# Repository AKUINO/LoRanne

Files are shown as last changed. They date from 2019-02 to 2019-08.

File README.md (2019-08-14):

# Long Range (LoRa) Radio Sensors for AKUINO
After connecting wired 17 sensors to a single AKUINO, we were convinced that wireless is very useful...

With the advent of LoRA transmission technology which ensures a really good indoor range, with the availability of ready to use modules like AdaFruit Feather M0 able to transmit data for years with simple batteries, we are convinced that a very performant solution can be created.
## Hardware

Transmitters (working on batteries, collecting and transmitting sensors data, sleeping most of the time) are explained further here: https://github.com/AKUINO/RadioSensor/tree/master/transmitter

Receiver(s) (powered, collecting transmitted data, archiving it locally, transmitting on Internet, never sleeping) is explained further here: https://github.com/AKUINO/RadioSensor/tree/master/receiver

General design considerations:

* Transmitters: Arduino MKR WAN 1300 https://store.arduino.cc/mkr-wan-1300 (was AdaFruit Feather M0: https://www.adafruit.com/product/3179 but AdaFruit products are rarely certified "CE")
* Receiver: for transmitters, we are also switching to an integrated "CE" marked product, M5STACK Code Module: https://m5stack.com/collections/m5-core
* 1-Wire sensors have the advantage of being self-identified, "hot-pluggable" and could be connected to one sensor node or another: https://www.maximintegrated.com/en/app-notes/index.mvp/id/4206
  * Serial adapter for 1-Wire gives better reliability than bit-banging (e.g. https://www.mikroe.com/uart-1-wire-click ) but requires 5V. As most 1-Wire devices are happy (but sometimes slower) at 3.3V, fewer devices not too far away will make bit-banging possible.
  * Thermocron (IButton: https://be.farnell.com/fr-BE/c/semiconducteurs-circuits-integres/memoires/accessoires-iboutons/iboutons ) can receive a "mission" and record temperature OFF-LINE for very long period of time: they can be used to ensure cold-chain continuity during transportation. They can even be programmed by a remote radio module: http://arduinofun.blogspot.com/2010/04/arduino-ibutton-data-logger-programmer.html . We have programmed data download and missioning of Thermocron by ELSA
  * Mains Switch: https://www.axiris.eu/en/index.php/1-wire/1-wire-mains-switch
* I2C sensors are often working at 3.3V and 5V. Short wires though (20 cm max: should be in the same box than the radio module)
  * I2C CO2+temperature+humidity: https://befr.rs-online.com/web/p/products/1720552/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|Temperature_And_Humidity_Sensors-_-PRODUCT_GROUP&matchtype=&pla-544508151584&gclid=Cj0KCQiAzKnjBRDPARIsAKxfTRA_NGOGs_dE9fBuCA61ZyCIf1GovlkXcqFPyUBE3JYgCDP7rXKEHxUaAuaREALw_wcB&gclsrc=aw.ds
  * I2C Temperature and/or humidity: https://befr.rs-online.com/web/c/semiconductors/sensor-ics/temperature-sensors-humidity-sensors/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,4294510394,4294490065,4294505396,4294510395,4294510203,4294356324,4294821500 and also https://www.tindie.com/products/akdracom/temperature-humidity-sensor-probe-precision-ic/
  * Grove Wiring standard is often used and is similar to QWIIC from Sparkfun: https://www.sparkfun.com/qwiic (Grove as a normal pitch connector, Sparkfun is smaller; Beware: AdaFruit standard is different!):
  1. Yellow - SCL
  1. White - SDA (Blue for QWIIC)
  1. Red - VCC on all Grove Connectors
  1. Black - GND on all Grove Connectors
  M5Stack Core is equipped with a Grove I2C connector.
* Lithium Battery: https://shop.mchobby.be/accu-et-regulateur/746-accu-lipo-37v-4400mah-3232100007468.html , https://be.farnell.com/fr-BE/mikroelektronika/mikroe-1120/batterie-lithium-polymer-3-7v/dp/2786900 , https://www.onlylipo.com/21-1s-37-volts-1-element
* Enclosures:
  * We selected KRADEX 64mm x 88mm x 42mm: https://www.tme.eu/fr/details/z-56jh-abs/boitiers-universels/kradex/z56jh-abs/ looking like CEL-MAR 1-Wire boxes that we also use.
  * 8 x 8cm, 5cm deep: many electrical junction boxes
  * 10 x 10cm, 6cm deep: http://be.farnell.com/fr-BE/fibox/pcm-95-60-g/coffret-boite-polycarbonate-gris/dp/2473443

## Software
* RadioHead libraries: http://www.airspayce.com/mikem/arduino/RadioHead/index.html Be sure to use the latest version (1.89)
  * for LoRa: http://www.airspayce.com/mikem/arduino/RadioHead/classRH__RF95.html

* 1-wire:
  * Host driver: https://www.maximintegrated.com/en/products/ibutton/software/1wire/wirekit.cfm
  * Recommended by Adafruit: https://www.pjrc.com/teensy/td_libs_OneWire.html
  * Slave device emulation library: https://github.com/orgua/OneWireHub (in case we want to connect to host through 1-wire)

* AdaFruit Feather M0, Arduino IDE SAMD support: https://learn.adafruit.com/adafruit-feather-m0-basic-proto/using-with-arduino-ide

## LoRa
* Allowed duty cycle and power in different 868MHz bands: https://www.disk91.com/2017/technology/internet-of-things-technology/all-what-you-need-to-know-about-regulation-on-rf-868mhz-for-lpwan/ From this document, the best local bandwidth could be 869,3 to 869,4 limited to 10mW but with no duty cycle constraint.
  * We measured 7 packets of 37 characters per seconds when testing this radio band.  
* 433 MHz may not be allowed in production within Europe: the project may have to be announced as "RFID" if we stick to those frequencies
  * In this band, we reached 540 meters in a corn field (emmiter and receiver at the corn height; single wire antenna)
* Calculator of Allowed duty cycle for different LoRa configurations: https://docs.google.com/spreadsheets/d/1COg2J1at6j8meehTtvfj5TIiM8pbj4SvKf7sa-Oq5fU/edit#gid=1628588258
## Sensors
Each node can receive many kind of sensors and its firmware can be adapted for each situation: the USB programming port of the node can be used to either change the firmware or to access a terminal console and change parameters.

An important information is battery voltage: its value will always be read and transmitted (register 1).

### I2C
I2C runs on 5V but also on 3.3V (not all sensors but most). Wires must be kept very short (20cm max, less is better).

The commands are different for each type of sensors: the bus cannot be really "auto discovered" like with 1-Wire (see below). The only possible thing is to associate I2C addresses with possible devices...

### 1-Wire
1-Wire ensures auto-configuration (devices can be "discovered" on the bus). Each 1-Wire device have a unique 64 bits address which can be auto-discovered by polling the 1-Wire bus (owdir on Linux, the equivalent will have to be programmed using libraries like https://www.pjrc.com/teensy/td_libs_OneWire.html ). The 8 first bits of this address indicates a generic device type which will have to be known by the firmware to adapt itself to the characteristics of each device type (e.g. number of values, polling protocol, parasitic powering...). The 8 last bits are a CRC8 checksum of the 7 previous bytes. It must be verified after each transmission (wire or radio) to ensure data integrity.

List of existing device types: http://owfs.org/index.php?page=family-code-list

The device types that we really need to support at first are:
* 26 for the DS2438 Battery Monitor (used as an ADC for various types of sensors like RH, CO2...)
* 28 for the DS18B20 Temperature Sensor; a library directly supporting this device seems to exist: https://github.com/milesburton/Arduino-Temperature-Control-Library This may be the best way to start supporting some sensors...
* 01 for the DS1990 simulated by RFID badge reader

A central directory of 1-Wire devices will be kept locally but also in the Receiver (and in ELSA application).

Every minutes or 5 (or any delay set in configuration), the node will transmit the raw data (no scaling) read for the different sensors. The allocation table will be transmitted every hour (or delay set in configuration) or on request by the central node (after detection of a checksum mismatch with the allocation table).

Data will be processed by the sensor node to transmit only specific JSON data values like "temperature" and not all registers of the device.

## Messages
* Encryption: http://www.airspayce.com/mikem/arduino/RadioHead/classRHEncryptedDriver.html#details
* Header with:
  * "FROM" (for sensors, the id of current node; for central node, id to distinguish the right central node)
	  * encoded on one byte
  * "TO" (for sensors, id of their central node; for central node, 255 for broadcast or id of a specific node to be queried)
	  * encoded on one byte
  * "ID", for a given "FROM"-"TO"-"FLAGS" combination, is a sequence ID of the message (overflow at 255): it allows the receiver to detect it has missed messages (and take action to correct this situation if needed).
  * "FLAGS" specifies the type of message: sensors data vs actuators (registers) setting; retransmission request (messages missed by receiver, the receiver signals which ID are missing); devices table to identify connected 1-Wire or I2C devices (from sensor node to central); relaying (MESH protocol, to be designed)
  * Sensors Data message: see below

## Sensors Data Messages
There are many encoding formats (see bottom of https://github.com/AKUINO/JBCDIC/blob/master/README.md ).

Please look at our proposal, the project AKUINO/JBCDIC: https://github.com/AKUINO/JBCDIC !

## Protocol
* A potential source of inspiration: https://github.com/fredilarsen/ModuleInterface/blob/master/documentation/Protocol.md
* A remote module (sensors) is sleeping most of the time (does not listen to radio) and awakens from time to time (around 3 minutes) to collect data and send it to the central module.
* A central module is listening all the time and sends actuators settings (or retransmission requests) only just after receiving sensors data from a remote module.
* The sender listen to the air and wait for silence (random delay) to avoid collision (this is done by the radio chip SX127x but needs to be configured. Looking at RadioHead library source code, it can be done: https://github.com/adafruit/RadioHead/blob/master/RH_RF95.h ). This is called LBT (Listen Before Talk).
* The message is sent using RadioHead library (encrypted but no ACK required).
* For remote module, the sender keeps listening for eventual input messages from the destination (actuators settings, sensors data retransmission requests) during a short period of time.
* If a remote module notices that some actuators settings are missing, it requests their retransmission.
* Sensor nodes send their 1-Wire / I2C Allocation table either periodically (about an hour), either when some connection changes is detected or whenever a request for it is received from the central node
* Retransmission request: timestamp + pairs of bytes for each ID intervals ("begin ID"-"end ID") that needs to be (re)transmitted. Overflow may occur (increment of 255 is 0) and "end ID" can be lower than "begin ID".
* Retransmission: message with exactly the same Header (TO, FROM, ID, FLAGS) and Payload than the one transmitted before

All nodes will be responsible to keep a buffer of the last messages (254 last messages for sensors and 254 last messages for actuators) they sent.

Redundancy of central module is possible: the two modules then share the same ID. A central module may not have received a package and therefore ask to retransmit a message well received by the other module: redundant transmissions are therefore discarded based on ID+timestamp.

## Configuration
We will use a serial terminal (USB) to set the configuration parameters (ANSI character codes for colors). We have the necessary code in C++ for PIC32. The configuration will have to assign a key (0 to 31) to the physically connected ports:
* Digital inputs: for a 1st version, we will statically map some GPIO as 0/1 ports
* Analog inputs (12 bits): for a 1st version, we will statically map some ADC inputs including at least the battery level and 2 ADC lines
* Digital outputs (PWM, pull-up, delays) to be SET (based on messages received from central): for a 1st version, we will statically map some PWM lines with basic local configuration attributes.
* 1-Wire (multiple sensors: 1-Wire addresses AUTOMATICALLY mapped to different keys but a selection of registries may have to be done based on the device type. ABANDONED for now due to lack of 5V...)
* Serial link (not for a 1st version except if a precise need arise)
* Campbell SDI (not for a 1st version except if a precise need arise)
* I2C device initialization command and register read: this is not well standardized but we will try to orthogonalize the possibilities.
A basic polling cycle (e.g. 3 minutes) has to be set. Each key can be obtained either at each poll or at a configured multiple.

## References
* The Ten Commandments of Wireless Communications: http://www.bb-elec.com/Learning-Center/All-White-Papers/Wireless-Cellular/10-Commandments-of-Wireless-Communications/10_Commandments_Wireless_WP033_R2-1112.pdf
* Detailed RadioHead interface: https://github.com/adafruit/RadioHead/blob/master/RH_RF95.h
* The standard pinout of Feather M0 is: https://cdn-learn.adafruit.com/assets/assets/000/046/244/original/adafruit_products_Feather_M0_Basic_Proto_v2.2-1.png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
* Similar project but for very long range: http://cpham.perso.univ-pau.fr/LORA/WAZIUP/FAQ.pdf
  * http://cpham.perso.univ-pau.fr/LORA/WAZIUP/SUTS-demo-slides.pdf
* CayenneLPP: https://mydevices.com/cayenne/docs/lora/#lora-cayenne-low-power-payload
* PJON, an alternative transmission protocol: https://github.com/fredilarsen/ModuleInterface/blob/master/documentation/Protocol.md
* PlugAndPlay mechanism for small IoT networks using "off the shelf" sensors: http://pitkaaho.net/varasto/2013_IJSNet.pdf
* MainFlux does not seems to be locking anything (to double check!) and is involved in FIWARE and is very near of a good gateway for ELSA: https://www.mainflux.com/index.html
* LORD-MicroStrain is locking by the hardware : https://github.com/LORD-MicroStrain/
* UbiWorX is locking by the platform: https://ubiworx.com/documentation/introduction/introduction.html
* W3C API: https://w3c.github.io/sensors/

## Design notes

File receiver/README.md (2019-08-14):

# Receiver (Data Sink)
One or more gateway (receiver) can collect the data emitted by the different transmitters (radio modules with sensors connected).

The receiver(s) is always listening (never sleeps) and responds immediately when it receives a message:
1. it acknowledges the received message
1. if a further answer is needed (current time for instance), it sends it immediately

The receiver is archiving all the messages it receives. This archive is stored on a SD card which may be removed (the receiver is therefore a data logger).

The receiver sends the received data to the ELSA web application (decompressed and re-expanded to valid JSON but without semantic interpretation). The archived data on the SD card is also useful when Internet is interrupted (even for a very long time): all data can be sent when comunications resume.

The receiver synchronizes its clock with Internet (when available) and store the current date/time in the local RTC.

A small OLED display shows the communication statuses (LoRa, Internet), the latest data received and the possible alarms.

## Hardware

The receiver is a simple stack of the following AdaFruit boards (from bottom to top):
1. SD Card and Real Time Clock: https://www.adafruit.com/product/2922
1. LoRa Radio: https://www.adafruit.com/product/3231
1. HUZZAH32 ESP32 Feather: https://www.adafruit.com/product/3405
1. 128x32 OLED Add-on For Feather: https://www.adafruit.com/product/2900

The enclosure is big enough to guest a 18650 battery for continuous operation even during a long power breakdown.

To have "CE" marked hardware, we will be using M5Stack Core module in the future. It integrates in a sleek package:

    USB Type-C connector (Power and Programming)
    ESP32-based: 4 MByte flash + 520K RAM
    Speaker, 3 Buttons, Color LCD(320*240), 1 Reset
    WiFi 2.4G Antenna: Proant 440
    SD card slot (16G Maximum size)
    Battery Socket & 150 mAh Lipo Battery
    Bus Extension Pins & Holes
    Grove Port

### Pinout

PCB Pin|ESP32 Pin|Remark
-------|---------|------
RST||MCU Reset
3V|Vcc|3V3 power, 250ma for MCU, 250ma available for all other boards
NC||Not connected
GND|GND|GROUND common to all boards
A0|GPIO 26|Relay 1 enable. ADC not working when Wifi works
A1|GPIO 25|Relay 1 disable. ADC not working when Wifi works
A2|GPI 34|Input only!
A3|GPI 39|Input only!
A4|GPI 36|Input only!
A5|GPIO 4|Relay 2 disable. ADC not working when Wifi works
SCK|CLCK|SPI Clock (LoRa)
MO|MOSI|SPI output (LoRa)
MI|MISO|SPI input (LoRa)
RX|RX|Serial1 input
TX|TX|Serial1 output
21|GPIO 21|Relay 2 enable
-------|---------|------
BAT||Battery power
EN||3V3 regulator enable (disable if 3V3 power provided in another way)
USB||USB connector power
13|GPIO 13|Red LED on main board
12|GPIO 12|Pull down resistor
27|GPIO 27|LoRa A=Reset LoRa
33|GPIO 33|LoRa B=ChipSelect SD card
15|GPIO 15|Button A;LoRa C
32|GPIO 32|Button B;LoRa D=InterrupReQuest LoRa
14|GPIO 14|Button C;LoRa E=ChipSelect LoRa
SCL|SCL|I2C Clock (no pull-up)
SDA|SDA|I2C Data (no pull-up). OLED address=0x3C. RTC address=0x68

## Software

The software is a mirror of the one used by the transmitter. It must:
1. acknowledge data received to connecting transmitters (RadioHead Datagrams)
2. TO EVALUATE: assign a reduced numerical id for every string (name, 1-Wire ID, I2C peripheral, etc.) submitted by a transmitter: this allows compression of strings that may need to be transmitted by Radio. If the receiver fails, the transmitters can provide their local part of the dictionary when it restarts.
3. TODO: it retrieves sensors configuration (for the parameters needed to be known locally if any) from the ELSA web application. Those parameters are archived on the SD card in case of Internet failure. Amongst those parameters, alarm levels for some sensors, set points for opening/closing valves or switches, etc.
4. it sends data to the ELSA web application (also archived on the SD card)

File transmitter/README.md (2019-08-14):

# TRANSMITTER
In a "star" network there are modules collecting data in different places (transmitters) and one or two "data sinks" (receivers, gateways) that route the data to the data management application.

The transmitters must be as autonomous as possible (minimal configuration, automatic adaptation to new sensors put in place, agnostic about the data: it will be managed by the application, not the transmitter).

They include:
* power management: sensors are powered only when needed, battery power is saved as much as possible
* radio bandwidth management: radio transmission is minimized and assumed "dangerous": if it fails, data is kept up to the moment transmission can resume.

The configuration needed is minimal:
* a Network ID is provided once for all and needs a special boot-up sequence and password to be changed.
* a Network access key and a unique Module ID must be set. They remain normally unchanged. Another password protects those parameters.

The peripherals are automatically detected (1-Wire, I2C). Some may have to be configured (Analog or serial inputs). This is done through a wizard (sequence of questions with current answers provided by defaults).

Radio messages are buffered and exchanged in compressed URL format (see project [JBCDIC](https://github.com/AKUINO/JBCDIC/blob/master/README.md), aimed at compressiong JSON, used to compress URLs).

The transmitter is currently based on the Adafruit Feather M0 with a LoRa transmitter (https://www.adafruit.com/product/3178) but next version will be based on Arduino MKR WAN 1300. We add an underlying board to ease connections to sensors and to selectively power them. The following table explains the pinout:

Connector|Code|Data Pin|Power Activation Pin|Remark
---------|----|--------|--------------------|------
J1-1|g|||GND
J1-2|T|TX (15)|A3 (8)|Serial TX, 10k pull-up
J1-3|R|RX (14)||Serial RX
J1-4|v||A3 (8)|Switched and limited Vcc (see below)
J1-5|g|||GND
J1-6|C|SCL (18)|D11 (23)|I2C clock, 5k pull-up
J1-7|D|SDA (17)|D11 (23)|I2C data, 5k pull-up
J1-8|v||D11 (23)|Switched and limited Vcc (see below)
J1-9|g|||GND
J1-10|O|D13 (25)||LED: Switched Vcc but limited (see below) and 100 ohm
J1-11|I|A0 (5)||Button switch; Analog input protected and filtered for 50Hz
J1-12|v|||Unswitched Vcc limited by 100 ohm
J2-1|g|||GND
J2-2|1|A1 (6)||Analog input protected and filtered for 50Hz
J2-3|v||A4 (9)|Switched and limited Vcc (see below)
J2-4|g|||GND
J2-5|2|A2 (7)||Analog input protected and filtered for 50Hz
J2-6|v||A5 (10)|Switched and limited Vcc (see below)
J2-7|g|||GND
J2-8|W|D5 (19)|D12 (24)|1-Wire bus, 5k pull-up
J2-9|v||D12 (24)|Switched and limited Vcc (see below)
J2-10|10|D10 (22)||Switched and limited Vcc (see below)
J2-11|6|D6 (20)||Switched and limited Vcc (see below)
J2-12|v7||D12 (24)|Switched 7 volts to power RFID/NFC reader (small DC/DC converter from D12)

Distributed power is switched by a TBD62783APG DMOS transistor array (clamping diode included), limited by a 300ma temporary fuse, a 18µH inductance and sustained by a 3µF capacitor.

Detailed Eagle schema and board definition are in this directory.

## Data transmitted

Data is encoded as an URL using JBCDIC ( https://github.com/AKUINO/JBCDIC ). A message is made of only one (for now) session of measures up to the LoRa maximum size (53 bytes in our case).

One measurements session is a URL (in the future: a JSON object) with the following properties:

Property|Connection|Pin|Description
--------|----------|---|-----------
H0|||Seconds ellapsed since module startup. H0 is replaced by H with the correct time by the receiver before resending to the Web application
H|||Seconds since 01/01/2019 (if time was broadcasted by receiver ("data sink") and synchronized with transmitter)
N|||Network Identification number: Not transmitted but added by the receiver before resending to the Web application
M|||Radio Module Identification number: Not transmitted but added by the receiver before resending to the Web application
R|||RSSI for this message: Not transmitted but added by the receiver before resending to the Web application
A0|J1-11|A0|Button pressed? Not transmitted if 0
A1|J2-2|A1|Analog input 1. Not transmitted if 0
A2|J2-5|A2|Analog input 2. Not transmitted if 0
B||A6|Battery voltage
B5||A7|USB voltage (if present). Usually 5 volts if connected
B9|||Last RSSI of messages broadcasted by Receiver (decimal)
C|J1-3|RX|Serial data received (string)
Dnnn|J2-8|D5|Value (or array of values or object with different properties) obtained from 1-Wire device at address "nnn..." (decimal)
G|J2-8|D5|Last badge read by RFID reader (encoded in decimal). Not transmitted if none
G0|J1-10|D13|Button LED on? Not transmitted if not
G1|J2-10|D10|Yellow LED of RFID reader is on? Not transmitted if not
G2|J2-11|D6|Red LED of RFID reader is on? Not transmitted if not
Innn|J1-7|I2C|Value (or array of values or object with different properties) obtained from I2C device at address "nnn" (decimal)

### Data transmission example

Before compression to 4 bits per character:
`{H0+3602A0+1B+3-12B9-78D159300978176+27-2I68[+27-5+40-5]}`
which means:
* `H0+3602` : 3602 seconds elapsed since starting the radio module
* `A0+1` : Button is pressed
* `B+3-12` : Battery is 3.12V
* `B9-78` : Last RSSI was -78 (in decimal)
* `D159300978176+27-2` : the temperature sensor address is 0x2517140600 (not including the leading 0x28 indicating its type and the trailing byte providing an CRC) and its temperature is 27.2°C
* `I68[+27-5+40-5]` : the I2C device at address 0x44 (usually an SHT31 sensor) provides two values: 27.5°C and 40.5% rH

The receiver will receive this data and retransmit it to the Internet application in standard JSON and adding network/module identification:

~~~~
  [ { H:(date/time in seconds elapsed since 1/1/1970 as in UNIX),
     N:1,   (network id)
     M:3,   (module id)
     R:-77,   (RSSI of transmitted message)
     A0:1,     
     B:3.12,    
     B9:-78,    
     D159300978176:27.2,    
     I68:[27.5,40.5]   
    } 
  ]
~~~~

## Software
* Radiohead library for encrypted Lora transmissions
* Protohead for simultaneous execution of data collection and radio transmission
* Periodical wake-ups for collection of sensors values and LoRa transmission (Listen before talk, random delay)
* USB Serial port for the configuration wizard
* JBCDIC for data compression
* FIFO Round Robin Buffer for unacknowledged transmitted data
* Watchdog on button for immediate wakeup, NFC/RFID scan and immediate transmission of status data (including the "button pressed" indication)

## Extensions
* To control equipement in adverse electrical environments, insulation of 1-Wire bus may be useful:  http://www.ti.com/lit/ds/symlink/iso1540.pdf

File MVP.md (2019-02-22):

# Capteurs Radio LoRa / Produit viable minimal

Afin de réaliser rapidement un produit qui réponde à 90% des besoins avérés, ce document en liste les caractéristiques ainsi que les étapes de réalisation.

Il est en français car il est à usage de l'équipe aux commandes à Gembloux en ce printemps 2019...

## Spécifications du matériel

1. Module AdaFruit Feather M0 LoRa 868 MHz
1. Batterie LiPo la plus puissante possible dans les limites de taille du boîtier qui sera choisi
1. Boîtier mural pouvant s'ouvrir (vis de serrage) pour faire passer les fils ou capteurs requis tout en gardant une étanchéité IP65 ou plus. S'inspirer de https://cdn-learn.adafruit.com/downloads/pdf/3d-printed-case-for-adafruit-feather.pdf
1. Connexions:
   1. Antenne interne ou externe ? Tester la différence de portée...
   1. Port USB "device" du AdaFruit Feather: pouvoir charger la batterie, pouvoir mettre à jour le logiciel, pouvoir configurer sans ouvrir le boîtier (bouchon en caoutchouc au dessus du port?) 
   1. Alimentation 3V3 commutable (MOSFET? Denis va nous conseiller) pour les périphériques ("high side" ou "low side"?)
   1. Périphériques I2C en chaîne (connecteurs Grove: 4=GND - 3=3V3 - 2=SDA - 1=SCL) de 20cm ou moins.
   1. Port RS-232 (balance, sonde pH, etc.) avec convertisseur de niveaux du genre MAX3232. Idéalement le signal DCE (ou autre?) devrait être lié à un GPIO indiquant si le micro-contrôleur est endormi ou non.
   1. (combien?) Ports GPIO en entrée ou en sortie (bornier à vis), protections sans doute nécessaire (décharges électrostatiques, surtensions, court-circuit...)
   1. (combien?) Ports ADC en entrée (bornier à vis), protections sans doute nécessaire (décharges électrostatiques, surtensions...)
   1. Plusieurs points de connexions devraient être prévus pour la terre (GND) et le VCC (ou le VCC commuté) afin de pouvoir assembler des composants discrets (résistances) pour protéger les entrées.
   1. Bouton "reset" ou ON/OFF pour redémarrer sans devoir ouvrir (panne) ? S'inspirer de https://cdn-learn.adafruit.com/downloads/pdf/on-slash-off-switches.pdf?timestamp=1550577849

## Spécifications du logiciel

1. Voir le README.md ...
1. On préallouera les registres de configuration et de réception des données (pas de nécessité de gérer une allocation dynamique pour le moment): voir plus loin
1. Réseau en étoile (pas de relais "MESH") avec un "data sink" Central (connexion à Internet) pour le moment
1. Bande 10mW (pas de limite d'utilisation)
1. Sortie du Central par le port USB (Série), une ligne par paquet reçu avec encodage "URL": ...?clé=valeur&clé=valeur...
1. Commandes de paramétrage aussi sous forme d'URL: ...?clé=valeur&clé=valeur&...&clé=valeur

## Tableau des Périphériques ("output" du module)

On tient compte du "pinout": https://cdn-learn.adafruit.com/assets/assets/000/046/254/original/feather_Feather_M0_LoRa_v1.2-1.png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

* TIME, 4 octets: "timestamp" d'envoi: Horloge synchronisée par les messages du Central (data sink)
* BATT, Registre 1, 2 octets: Voltage en mV: Niveau de la batterie
* RSSI, Registre 2, 1 octet: RSSI de réception des messages envoyés par le Central (data sink)
* RX, Registre 3, un ou plusieurs blocs de 1 à 8 octets: données du Port Série (RS232); broches marquées "RX" et "TX"
* I2C: broches marquées "SDA" et "SCL"
  * TEMP, Registre 4, 2 octets: I2C Température en °C x 100
  * RH, Registre 5, 2 octets: I2C Humidité en %rH (% x 100)
  * LUM, Registre 6, 2 octets: I2C Luminosité (0 à 1000 environ)
  * Registre 7 à 11: I2C expansion...
* ADC0 à ADC5, Registre 12 à 17, 2 octets: ADC, broches marquées "A0" à "A5"
* IO09 à IO13, Registre 18 à 23, 0/1: GPIO, broches marquées "9" à "13"
* Broches marquées "5" et "6": contrôle du VCC pour les périphériques, contrôle de flux pour le RS232?
* Autres ?

## Tableau de configuration des Périphériques (paramétrage du module)

On utilisera les mêmes numéros de registres que pour la sortie et les mêmes identifiants dans l'URL d'entrée sauf pour RX qui devient TX...

# Connexion du récepteur central à Internet

Ce module peut soit collecter les données provenant de sondes LoRa mais en plus des données provenant de capteurs locaux.

1. Module AdaFruit Feather M0 LoRa 868 MHz
1. Module AdaFruit FeatherWing Ethernet (connexion Internet par fil allant au routeur): https://www.adafruit.com/product/3201
1. Batterie LiPo comme alimentation de secours en cas de panne de courant
1. Boîtier (protection de niveau "domestique") laissant passer les fils ou capteurs requis
1. Connexions:
   1. Antenne interne ou externe ? Tester la différence de portée...
   1. Port Ethernet (cable UTP de 1 mètre jusqu'au routeur)
   1. Port USB "device" du AdaFruit Feather: alimenter le module, pouvoir charger la batterie, pouvoir mettre à jour le logiciel, pouvoir configurer sans ouvrir le boîtier. Se connecte au port USB du routeur interne (cable USB de 1 mètre jusqu'au routeur ou 3 mètres si jusqu'à un chargeur mural)
   1. Périphériques I2C en chaîne (connecteurs Grove: 4=GND - 3=3V3 - 2=SDA - 1=SCL) de 20cm ou moins.
   1. Port RS-232 (balance, sonde pH, etc.) avec convertisseur de niveaux du genre MAX3232. Idéalement le signal DCE (ou autre?) devrait être lié à un GPIO indiquant si le micro-contrôleur est endormi ou non.
   1. (combien?) Ports GPIO en entrée ou en sortie (bornier à vis), protections sans doute nécessaire (décharges électrostatiques, surtensions, court-circuit...)
   1. (combien?) Ports ADC en entrée (bornier à vis), protections sans doute nécessaire (décharges électrostatiques, surtensions...)
   1. Plusieurs points de connexions devraient être prévus pour la terre (GND) et le VCC (ou le VCC commuté) afin de pouvoir assembler des composants discrets (résistances) pour protéger les entrées.
   1. Bouton "reset" ou ON/OFF pour redémarrer sans devoir ouvrir (panne) ? S'inspirer de https://cdn-learn.adafruit.com/downloads/pdf/on-slash-off-switches.pdf?timestamp=1550577849

# Connecter un périphérique RS232 à une application existante sur tablette (ou smartphone)

On veut connecter tout périphérique série à une tablette et envoyer des données au clavier de la tablette (ou smartphone. Ces données peuvent commencer par un caractère "accent grave" pour que ELSA le reconnaisse comme début d'une opération spéciale (par exemple stocker la donnée transmise). Ceci pourra servir aux balances, aux lecteurs de pH, etc.

On utiliserait le même matériel que pour une sonde radio mais en remplaçant le module Adafruit par un "BlueFruit": https://www.adafruit.com/product/3406 .

Au niveau logiciel il faut alors un sketch implantant un Bluetooth HID: https://learn.adafruit.com/adafruit-feather-m0-bluefruit-le/hidkeyboard .

On pourrait de plus connecter tout type de capteur I2C (ou autre) avec tout type de smartphone ou de tablette.

# Connecter toute une série de capteurs à Internet (WiFi ou Ethernet):

Ce module peut envoyer les données collectées par WiFi ou par Ethernet.

1. Module AdaFruit Feather M0 Wifi: https://learn.adafruit.com/adafruit-feather-m0-wifi-atwinc1500
1. Option: Module AdaFruit FeatherWing Ethernet (connexion Internet par fil allant au routeur): https://www.adafruit.com/product/3201
1. Batterie LiPo comme alimentation de secours en cas de panne de courant
1. Boîtier pour coffret électrique (rail DIN)
1. Coffret électrique ABB Mistral (IP65) de taille adéquate
1. Serres étoupes (passe-cable) amovibles selon les besoins
1. Périphériques I2C avec entrées/sorties protégées et support pour rail DIN: https://www.ereshop.com/shop/index.php?main_page=index&cPath=143
1. Alimentation électrique 5.2V: https://www.conrad.fr/p/alimentation-rail-din-tracopower-tbl-015-105-52-vdc-24-a-12-w-1-x-511941
1. Connexions:
   1. Antenne interne ou externe ? Tester la différence de portée...
   1. Port Ethernet (cable UTP de 1 mètre jusqu'au routeur)
   1. Port USB "device" du AdaFruit Feather: alimenter le module, pouvoir charger la batterie, pouvoir mettre à jour le logiciel, pouvoir configurer sans ouvrir le boîtier. Se connecte au port USB du routeur interne (cable USB de 1 mètre jusqu'au routeur ou 3 mètres si jusqu'à un chargeur mural)
   1. Périphériques I2C en chaîne (connecteurs Grove: 4=GND - 3=3V3 - 2=SDA - 1=SCL) de 20cm ou moins.
   1. Port RS-232 (balance, sonde pH, etc.) avec convertisseur de niveaux du genre MAX3232. Idéalement le signal DCE (ou autre?) devrait être lié à un GPIO indiquant si le micro-contrôleur est endormi ou non.
   1. (combien?) Ports GPIO en entrée ou en sortie (bornier à vis), protections sans doute nécessaire (décharges électrostatiques, surtensions, court-circuit...)
   1. (combien?) Ports ADC en entrée (bornier à vis), protections sans doute nécessaire (décharges électrostatiques, surtensions...)
   1. Plusieurs points de connexions devraient être prévus pour la terre (GND) et le VCC (ou le VCC commuté) afin de pouvoir assembler des composants discrets (résistances) pour protéger les entrées.

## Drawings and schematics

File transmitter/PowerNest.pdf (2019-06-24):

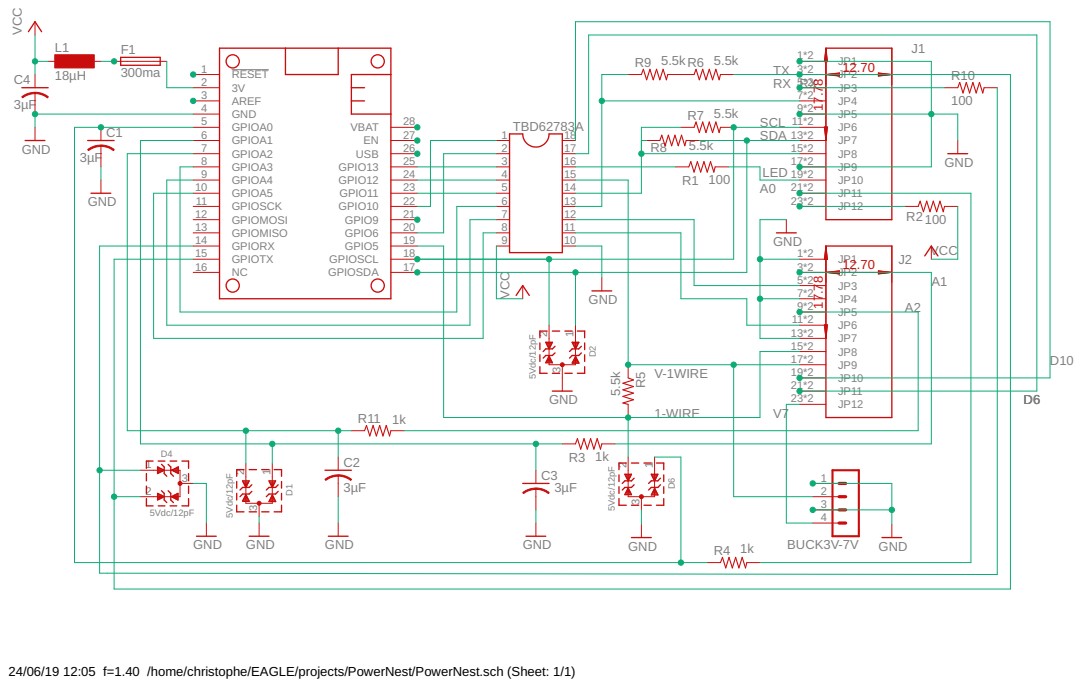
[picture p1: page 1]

5 | VBAT EN USB GPIO10 GPIO9 GPIO6

24/06/19 12:05 f=1.40 /home/christophe/EAGLE/projects/PowerNest/PowerNest.sch (Sheet: 1/1)

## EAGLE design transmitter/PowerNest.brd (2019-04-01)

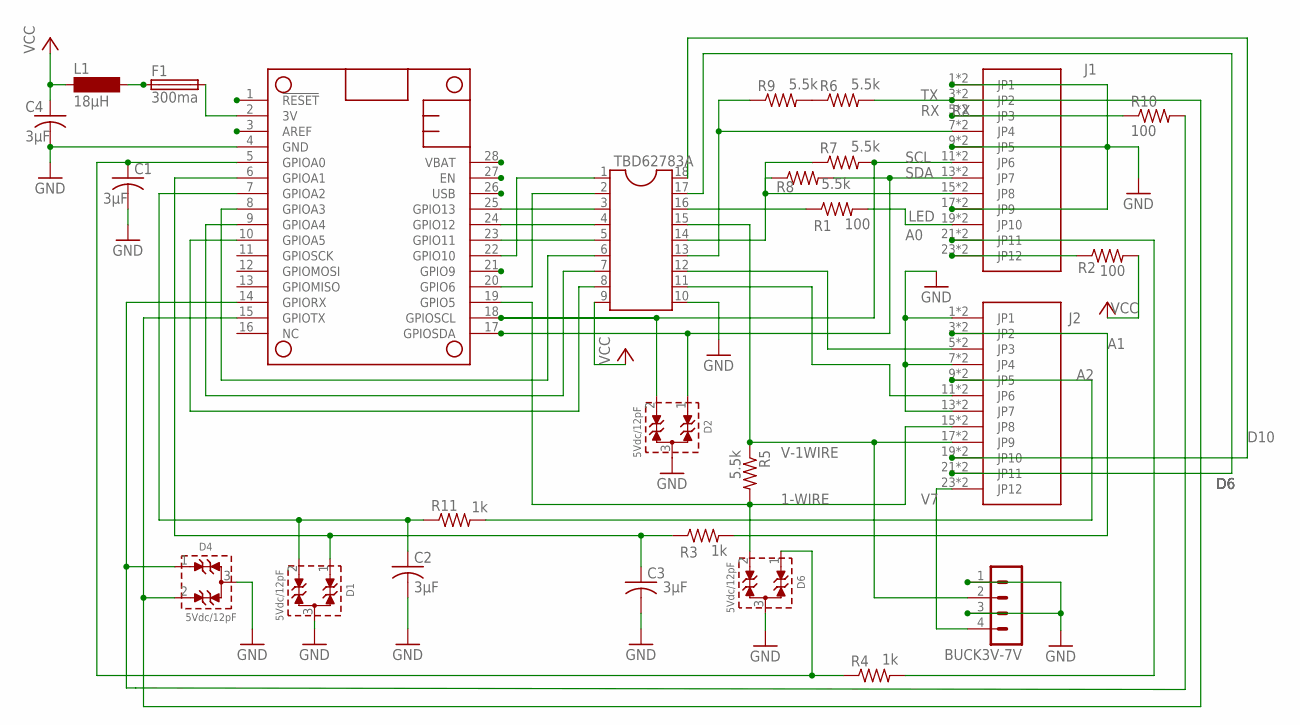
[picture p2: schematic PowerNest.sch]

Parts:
BUCK3V-7V: MA04-1
C1, C2, C3, C4: 3µF; C1206K
D1, D2, D4, D6: 5Vdc/12pF; WE-TVS_SOT23-3L
F1: 300ma; TE5
FEATHER: FEATHERWING_NODIM; FEATHERWING_DIM
J1, J2: MC000008B; CONNECTED
L1: 18µH; BS11
R1, R2, R10: 100; R1206
R3, R4, R11: 1k; R1206
R5, R6, R7, R8, R9: 5.5k; R1206
TBD62783A: DIL18S; SOCKET-18

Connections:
1-WIRE: D6.2 (I/O2), FEATHER.19 (GPIO5), J2.15 (JP8), J2.16 (JP8), R5.2
3V: F1.2, FEATHER.2 (3V)
A0: J1.21 (JP11), J1.22 (JP11), R4.2
A1: J2.3 (JP2), J2.4 (JP2), R3.2
A2: J2.9 (JP5), J2.10 (JP5), R11.2
D6: J2.21 (JP11), J2.22 (JP11), TBD62783A.17
D10: J2.19 (JP10), J2.20 (JP10), TBD62783A.18
GND: BUCK3V-7V.1, BUCK3V-7V.3, C1.2, C2.2, C3.2, C4.2, D1.3 (GND), D2.3 (GND), D4.3 (GND), D6.3 (GND), FEATHER.4 (GND), J1.1 (JP1), J1.2 (JP1), J1.9 (JP5), J1.10 (JP5), J1.17 (JP9), J1.18 (JP9), J2.1 (JP1), J2.2 (JP1), J2.7 (JP4), J2.8 (JP4), J2.13 (JP7), J2.14 (JP7), TBD62783A.10
LED: J1.19 (JP10), J1.20 (JP10), R1.2
unnamed: FEATHER.25 (GPIO13), TBD62783A.3
unnamed: FEATHER.8 (GPIOA3), TBD62783A.6
unnamed: FEATHER.24 (GPIO12), TBD62783A.4
unnamed: FEATHER.23 (GPIO11), TBD62783A.5
unnamed: FEATHER.9 (GPIOA4), TBD62783A.7
unnamed: FEATHER.10 (GPIOA5), TBD62783A.8
unnamed: F1.1, L1.2
unnamed: J1.15 (JP8), J1.16 (JP8), R7.1, R8.1, TBD62783A.14
unnamed: J1.7 (JP4), J1.8 (JP4), R9.1, TBD62783A.13
unnamed: C3.1, D1.1 (I/O1), FEATHER.6 (GPIOA1), R3.1
unnamed: C2.1, D1.2 (I/O2), FEATHER.7 (GPIOA2), R11.1
unnamed: R6.1, R9.2
unnamed: J2.5 (JP3), J2.6 (JP3), TBD62783A.12
unnamed: J2.11 (JP6), J2.12 (JP6), TBD62783A.11
unnamed: D4.1 (I/O1), FEATHER.14 (GPIORX), R10.2
unnamed: R1.1, TBD62783A.16
unnamed: J1.23 (JP12), J1.24 (JP12), R2.1
unnamed: C1.1, D6.1 (I/O1), FEATHER.5 (GPIOA0), R4.1
unnamed: FEATHER.22 (GPIO10), TBD62783A.1
unnamed: FEATHER.20 (GPIO6), TBD62783A.2
RX: J1.5 (JP3), J1.6 (JP3), R10.1
SCL: D2.2 (I/O2), FEATHER.18 (GPIOSCL), J1.11 (JP6), J1.12 (JP6), R7.2
SDA: D2.1 (I/O1), FEATHER.17 (GPIOSDA), J1.13 (JP7), J1.14 (JP7), R8.2
TX: D4.2 (I/O2), FEATHER.15 (GPIOTX), J1.3 (JP2), J1.4 (JP2), R6.2
USB: FEATHER.26 (USB)
V7: BUCK3V-7V.4, J2.23 (JP12), J2.24 (JP12)
V-1WIRE: BUCK3V-7V.2, J2.17 (JP9), J2.18 (JP9), R5.1, TBD62783A.15
VBAT: FEATHER.28 (VBAT)
VCC: C4.1, L1.1, R2.2, TBD62783A.9

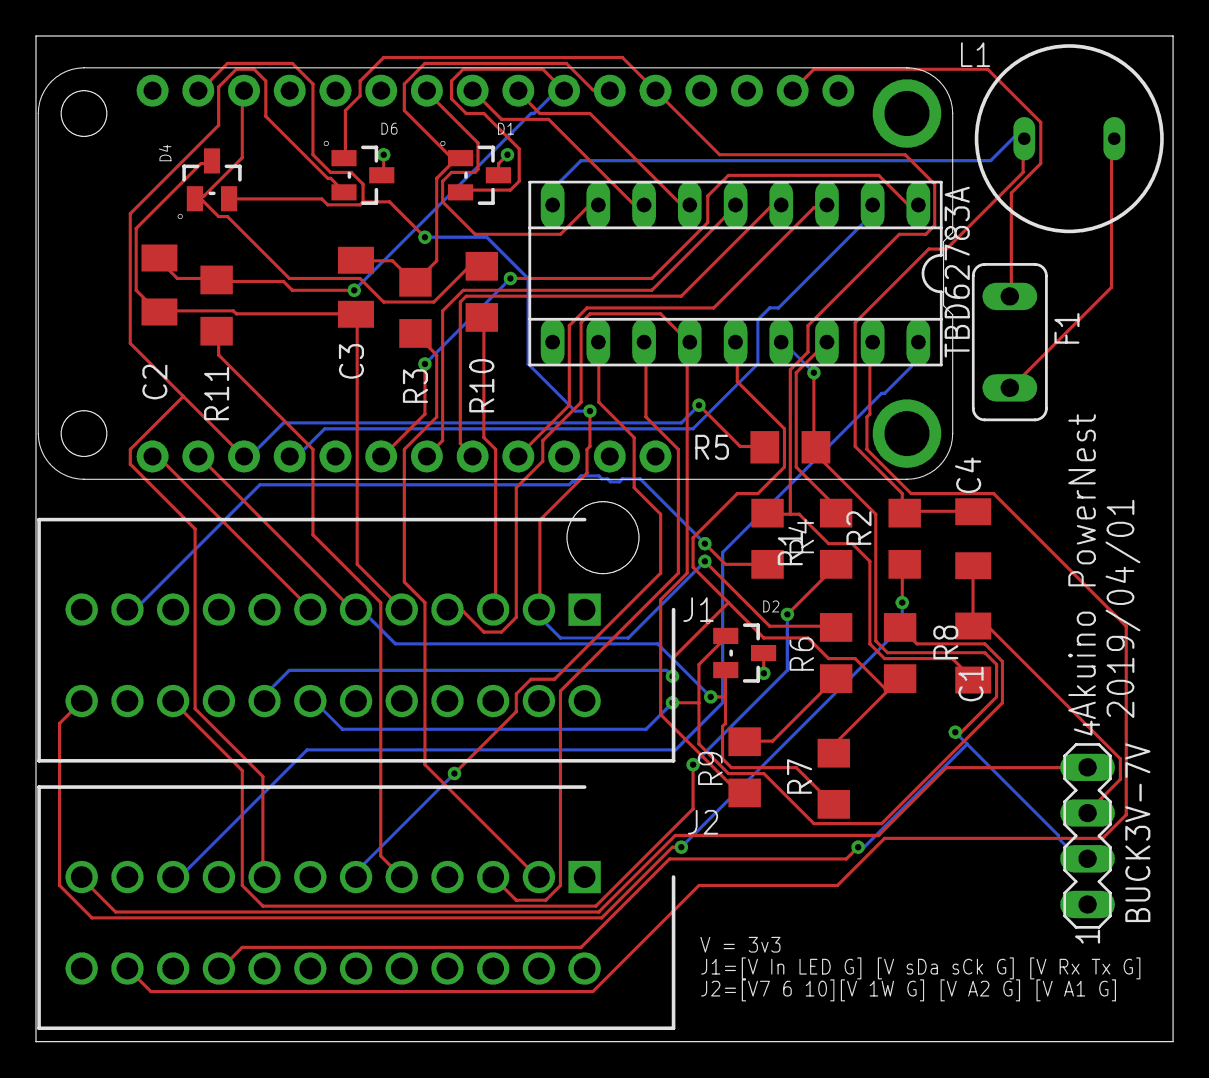
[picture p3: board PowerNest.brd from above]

Board: 2 copper layers, 63.2 x 55.9 mm, 26 parts (0 on the bottom side), 36 nets.

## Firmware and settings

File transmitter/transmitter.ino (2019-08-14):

/*
          _          _                   _____
    /\   | |        (_)                 / ____|
   /  \  | | ___   _ _ _ __   ___ _____| (___   ___ _ __  ___  ___  _ __
  / /\ \ | |/ / | | | | '_ \ / _ \______\___ \ / _ \ '_ \/ __|/ _ \| '__|
 / ____ \|   <| |_| | | | | | (_) |     ____) |  __/ | | \__ \ (_) | |
/_/    \_\_|\_\\__,_|_|_| |_|\___/     |_____/ \___|_| |_|___/\___/|_|
Programme de check-up + envoie des données sur le GateWay via LoRa
*/
// Could be an interactive compilation parameter
#define SENSOR_ID 4
#define SERVER_ADDRESS 120
#define SENSOR_INTERVAL 29
#define EPOCH_TIME 946684800

#include <Wire.h>
#include <OneWire.h>
#include <SPI.h>
#include <avr/dtostrf.h>
#include "Adafruit_SHT31.h"
#include "FIFO.h"
#include "pt.h"
#include "JBCDIC.h"

#include <RTCZero.h>
RTCZero zerortc;

Adafruit_SHT31 sht31 = Adafruit_SHT31();
#include <RH_RF95.h>

// From Arduino library Lora.h
#ifdef ARDUINO_SAMD_MKRWAN1300
#define LORA_DEFAULT_SPI           SPI1
#define LORA_DEFAULT_SPI_FREQUENCY 250000
#define LORA_DEFAULT_SS_PIN        LORA_IRQ_DUMB
#define LORA_DEFAULT_RESET_PIN     -1
#define LORA_DEFAULT_DIO0_PIN      -1
#elif ADAFRUIT_FEATHER_M0
#define LORA_DEFAULT_SPI           SPI
#define LORA_DEFAULT_SPI_FREQUENCY 8E6 
#define LORA_DEFAULT_SS_PIN        8
#define LORA_DEFAULT_RESET_PIN     -1
#define LORA_DEFAULT_DIO0_PIN      3
#else
#define LORA_DEFAULT_SPI           SPI
#define LORA_DEFAULT_SPI_FREQUENCY 8E6 
#define LORA_DEFAULT_SS_PIN        10
#define LORA_DEFAULT_RESET_PIN     9
#define LORA_DEFAULT_DIO0_PIN      2
#endif

RH_RF95 radioDriver(LORA_DEFAULT_SS_PIN, LORA_DEFAULT_DIO0_PIN);
#include <RHReliableDatagram.h>
RHReliableDatagram rhRDatagram(radioDriver, SENSOR_ID);

/////////////////////////////
//Déclaration des sorties
/////////////////////////////
#ifdef ARDUINO_SAMD_MKRWAN1300
  //Sortie du 1-Wire
  #define ONEWIRE_OUTPUT ???
  #define ledPin ???
  #define v_OneWire ???
  #define v_I2C ???
  #define v_Analog1 ???
  #define v_Analog2 ???
  #define VBATPIN ???
#elif ADAFRUIT_FEATHER_M0
  //Sortie du 1-Wire
  #define ONEWIRE_OUTPUT 5
  #define ledPin 13
  #define v_OneWire 12
  #define v_I2C 11
  #define v_Analog1 A4
  #define v_Analog2 A5
  #define VBATPIN A7
#endif

OneWire  ds(ONEWIRE_OUTPUT);

///////////////////////////////////////
//Déclaration des variables
//////////////////////////////////////
// Set how often alarm goes off here
const byte alarmSeconds = 3;
const byte alarmMinutes = 0;
const byte alarmHours = 0;

#define interruptPin A2

volatile bool alarmFlag = false; // Start awake
volatile bool buttonFlag = false;

//Fréquence d'utilisation (par defaut 869.35 MHz)
float frequence_LoRa = 869.35;
//Bande passante utilisée (par defaut : 62,5 KHz)
long bande_passante_LoRa = 62500;
//Puissance utilisée (par defaut : 10 mW)
uint8_t puissance_signal_LoRa = 10;

//Compteur de millisecondes pour vérifier le système de badge
unsigned long previousMillis=0;
//Taille FIXE Maximale du buffer d'envoi LoRa
#define SIZE_BUFFER 100
uint32_t compteur = 0;
FIFO sensorFIFO;

static struct pt sensorAnalysisPT, sendingPT, receivingPT;
uint8_t tmpBuffer[SIZE_BUFFER];

void setup() {
  // Log terminal (high speed)
  //Serial.begin(115200);
  // Power for Serial1...
  pinMode(A3, OUTPUT);
  digitalWrite(A3, HIGH);
  Serial1.begin(9600);
  
  //Alimentation(Vcc) de la LED
  pinMode(ledPin, OUTPUT);
  digitalWrite(ledPin, LOW);
  //Alimentation(Vcc) du 1-Wire
  pinMode(v_OneWire, OUTPUT);
  digitalWrite(v_OneWire, LOW);
  //Alimentation(Vcc) du I²C
  pinMode(v_I2C, OUTPUT);
  digitalWrite(v_I2C, LOW);
  //Alimentation(Vcc) de l'analogique A4
  pinMode(v_Analog1, OUTPUT);
  digitalWrite(v_Analog1, LOW);
  //Alimentation(Vcc) de l'analogique A5
  pinMode(v_Analog2, OUTPUT);
  digitalWrite(v_Analog2, LOW);
  //On démarre le 1-Wire
  Wire.begin();

  zerortc.begin(); // Set up clocks and such
  zerortc.setEpoch(0);
  zerortc.setAlarmEpoch(zerortc.getEpoch() + SENSOR_INTERVAL);
  zerortc.enableAlarm(zerortc.MATCH_HHMMSS);
  zerortc.attachInterrupt(alarmMatch); // Set up a handler for the alarm
  
  PT_INIT(&sensorAnalysisPT);
  PT_INIT(&sendingPT);
  PT_INIT(&receivingPT);
  if(true/*Serial1*/) {
    //On allume la LED car on est connecté au serial (mode debug)
    digitalWrite(ledPin, HIGH);
    Serial1.println("########################################");
    Serial1.println("########## Akuino Sensor v17 ##########");
    Serial1.println("########################################");
    Serial1.print(epochToTime());
    Serial1.print(";D;Fréquence:");
    Serial1.print(frequence_LoRa);
    Serial1.print("MHz");
    Serial1.print(";Bande passante=");
    Serial1.print(bande_passante_LoRa);
    Serial1.print("KHz");
    Serial1.print(";Puissance=");
    Serial1.print(puissance_signal_LoRa);
    Serial1.print("mW");
    Serial1.print(";ID=" );
    Serial1.println(SENSOR_ID);
  }
}

void loop() {
  if (alarmFlag == true) {
    alarmFlag = false;  // Clear flag
    Serial1.print(epochToTime());
    Serial1.println(";D;Alarm triggered!");
  }
  if (buttonFlag == true) {
    buttonFlag = false;  // Clear flag
    Serial1.print(epochToTime());
    Serial1.println(";D;Button changed");
  }
  Serial1.print(epochToTime());
  Serial1.println(";I;Awaken");
  digitalWrite(ledPin, HIGH);

  sensorAnalysis(&sensorAnalysisPT);
  loRaSending(&sendingPT);
  //receiving(&receivingPT);

  if(true/*Serial1*/) {
    Serial1.print(epochToTime());
    Serial1.println(";D;Sleeping Microchip");
  }
  Serial1.print(epochToTime());
  Serial1.println(";I;Alarm set, sleeping now");
  //On coupe toute les alimentation
  digitalWrite(ledPin, LOW);
  compteur++;
  Serial1.flush();
  digitalWrite(A3, LOW);
  zerortc.setAlarmEpoch(zerortc.getEpoch() + SENSOR_INTERVAL);
  zerortc.enableAlarm(zerortc.MATCH_HHMMSS);
  zerortc.standbyMode();    // Sleep until next alarm match
  digitalWrite(A3, HIGH);
  delay(10);
}

////////////////////////////////////////////////////////////////////////
//Fonction pour la lecture de la température via le chip DS18B20 1-Wire
///////////////////////////////////////////////////////////////////////

float lecture_DS18B20(byte addr[8]) {
  byte i;
  byte present = 0;
  byte type_s;
  byte data[12];
  float celsius, fahrenheit;

  ds.reset();
  ds.select(addr);
  ds.write(0x44, 1); // start conversion, with parasite power on at the end

  delay(800); // maybe 750ms is enough, maybe not  // PROTOTHREAD
  // we might do a ds.depower() here, but the reset will take care of it.

  present = ds.reset();
  ds.select(addr);
  ds.write(0xBE); // Read Scratchpad

  if(true/*Serial1*/) {
    Serial1.print(epochToTime());
    Serial1.print(";D;Data = ");
    Serial1.print(present, HEX);
    Serial1.print(" ");
  }
  for ( i = 0; i < 9; i++) { // we need 9 bytes
    data[i] = ds.read();
    if (true/*Serial1*/) {
      Serial1.print(data[i], HEX);
      Serial1.print(";");
    }
  }
  if(true/*Serial1*/) {
    Serial1.print("CRC=");
    Serial1.print(OneWire::crc8(data, 8), HEX);
    Serial1.println();
  }

  // Convert the data to actual temperature
  // because the result is a 16 bit signed integer, it should
  // be stored to an "int16_t" type, which is always 16 bits
  // even when compiled on a 32 bit processor.
  int16_t raw = (data[1] << 8) | data[0];
  if (type_s) {
    raw = raw << 3; // 9 bit resolution default
    if (data[7] == 0x10) {
      // "count remain" gives full 12 bit resolution
      raw = (raw & 0xFFF0) + 12 - data[6];
    }
  } else {
    byte cfg = (data[4] & 0x60);
    // at lower res, the low bits are undefined, so let's zero them
    if (cfg == 0x00) raw = raw & ~7;  // 9 bit resolution, 93.75 ms
    else if (cfg == 0x20) raw = raw & ~3; // 10 bit res, 187.5 ms
    else if (cfg == 0x40) raw = raw & ~1; // 11 bit res, 375 ms
    //// default is 12 bit resolution, 750 ms conversion time
  }

  celsius = (float)raw / 16.0;
  fahrenheit = celsius * 1.8 + 32.0;
  if (true/*Serial1*/) {
    Serial1.print(epochToTime());
    Serial1.print(";D;Temperature = ");
    Serial1.print(celsius);
    Serial1.print(" Celsius, ");
    Serial1.print(fahrenheit);
    Serial1.println(" Fahrenheit");
  }
  //on retourne la valeur du capteur
  return(celsius);
}//end function

////////////////////////////////////////////////////////////////////////
//Fonction pour l'analyse des données recues par la GateWay
///////////////////////////////////////////////////////////////////////

void analyse_datas_recues(char* datas_recus) {
  //On extrait les 3 premiers caractères
  char code_message[3];
  memset(code_message, 0, 4);
  strncpy(code_message, datas_recus, 3);
  puts(code_message);
  if(true/*Serial1*/){
    Serial1.print(epochToTime());
    Serial1.print(";D;");
    Serial1.println(code_message);
  }
}

extern int sensorAnalysis(struct pt *pt) {
  PT_BEGIN(pt);
  /////////////////////////////////////////
  //Analyse et lecture des I²C disponibles
  ////////////////////////////////////////
  PT_WAIT_UNTIL(pt, (zerortc.getEpoch() >= (previousMillis + SENSOR_INTERVAL)));
  if (true/*Serial1*/) {Serial1.println("");}
  //Variable a envoyer via LoRa
  char buffer_a_envoyer[SIZE_BUFFER]="";
  //pourcentage de la batterie
  byte error, address;
  int nDevices;
  float fonction_return_value;
  char v1_string[5];
  ////////////////////////////////////
  //Récupération du niveau de batterie
  ////////////////////////////////////
  float measuredvbat = analogRead(VBATPIN);
  measuredvbat *= 2;    // we divided by 2, so multiply back
  measuredvbat *= 3.3;  // Multiply by 3.3V, our reference voltage
  measuredvbat /= 1024; // convert to voltage
  //On écrit le header(en-tête) du buffer_a_envoyer + Niveau de batterie
  //le "moins" permet d'écrire à gauche
  dtostrf(measuredvbat, -5, 3, v1_string);
  // 1st piece of data, no "&" before field code...
  snprintf(&buffer_a_envoyer[strlen(buffer_a_envoyer)], SIZE_BUFFER - strlen(buffer_a_envoyer), "B=%s", v1_string);

  ////////////////////////////////////////////////
  //Analyse et lecture des analogiques disponibles
  ////////////////////////////////////////////////
  int pinA0=0;
  int pinA1=0;
  int pinA2=0;

  pinA0=digitalRead(A0);
  pinA1=analogRead(A1);
  pinA2=analogRead(A2);

  //On écrit
  //le "moins" permet d'écrire à gauche
  dtostrf(pinA0, -1, 0, v1_string);
  //On récrit dans la variable du buffer
  snprintf(&buffer_a_envoyer[strlen(buffer_a_envoyer)], SIZE_BUFFER - strlen(buffer_a_envoyer), "&A0=%s", v1_string);
  //On écrit
  //le "moins" permet d'écrire à gauche
  dtostrf(pinA1, -1, 0, v1_string);
  //On récrit dans la variable du buffer
  snprintf(&buffer_a_envoyer[strlen(buffer_a_envoyer)], SIZE_BUFFER - strlen(buffer_a_envoyer), "&A1=%s", v1_string);
  //On écrit
  //le "moins" permet d'écrire à gauche
  dtostrf(pinA2, -1, 0, v1_string);
  //On récrit dans la variable du buffer
  snprintf(&buffer_a_envoyer[strlen(buffer_a_envoyer)], SIZE_BUFFER - strlen(buffer_a_envoyer), "&A2=%s", v1_string);
  if(true/*Serial1*/) {
    Serial1.print(epochToTime());
    Serial1.println(";I;Begin I²C analysis");
  }

  nDevices = 0;
  for(address = 1; address < 127; address++ ) {
    digitalWrite(v_I2C, HIGH);
    /* REMARQUE :
     * Le scanner utilise la valeur de retour de Write.endTransmisstion
     * pour voir si un périphérique a émit un accusé réception de l'adresse
     */
    Wire.beginTransmission(address);
    error = Wire.endTransmission();

    if (error == 0) {
      if (true/*Serial1*/) {
        Serial1.print(epochToTime());
        Serial1.print(";I;Sensor found at 0x");
        Serial1.println(address,HEX);
      }
      nDevices++;

      //////////////////////////////////
      //SHT31 : Température et humidité
      //Adresse I²C: 0x44
      /////////////////////////////////
      if (true/*Serial1*/) {Serial1.print(epochToTime());}
      if(address == 0x44) { //Adresse en Hexadécimal
        if (! sht31.begin(0x44)) {
          if (true/*Serial1*/) {Serial1.println(";E;H1 or T1 not connected");}
        }
        else {
          //on lit les informations de ce capteur
          float t = sht31.readTemperature();
          float h = sht31.readHumidity();

          if (!isnan(t)) {  // check if 'is not a number'
            if (true/*Serial1*/) {
              Serial1.print(";I;t = ");
              Serial1.print(t);
            }
          } else {
            if (true/*Serial1*/) {Serial1.print(";W;t = null");}
          }
          if (!isnan(h)) {  // check if 'is not a number'
            if (true/*Serial1*/) {
              Serial1.print(";H = ");
              Serial1.println(h);
            }
          } else {
            if (true/*Serial1*/) {Serial1.println(";W;H = null");}
          }
          //le "moins" permet d'écrire à gauche
          dtostrf(t, -5, 3, v1_string);
          //On récrit dans la variable du buffer
          snprintf(&buffer_a_envoyer[strlen(buffer_a_envoyer)], SIZE_BUFFER - strlen(buffer_a_envoyer), "&C1=%s", v1_string);
          //le "moins" permet d'écrire à gauche
          dtostrf(h, -5, 3, v1_string);
          //On récrit dans la variable du buffer
          snprintf(&buffer_a_envoyer[strlen(buffer_a_envoyer)], SIZE_BUFFER - strlen(buffer_a_envoyer), "&H1=%s", v1_string);
        }
      }
    }
    else if (error==4) {
      if(true/*Serial1*/){
        Serial1.print(epochToTime());
        Serial1.print("Erreur inconnue à l'adresse 0x");
      }
      if (address<16)
      if(true/*Serial1*/) {
        Serial1.print(epochToTime());
        Serial1.print(";E;Unknown error at 0x");
        Serial1.println(address,HEX);
      }
    }
    digitalWrite(v_I2C, LOW);
  }
  if (true/*Serial1*/) {Serial1.print(epochToTime());}
  if (nDevices == 0) {
    if(true/*Serial1*/){Serial1.println(";E;No device found");}
  }
  else {
    if(true/*Serial1*/){Serial1.println(";I;End I²C analysis");}
  }
  ///////////////////////////////////////////////////////
  //Analyse et lecture des 1-Wire disponibles en cours...
  ///////////////////////////////////////////////////////

  if(true/*Serial1*/) {
    Serial1.print(epochToTime());
    Serial1.println(";I;Begin 1-Wire analysis");
  }
  byte i;
  byte present = 0;
  byte data[12];
  byte addr[8];

  if (true/*Serial1*/) {Serial1.print(epochToTime());}
  if (!ds.search(addr)) {
    if(true/*Serial1*/){Serial1.println(";E;No 1-Wire detected");}
    
    //if(true/*Serial1*/){Serial1.println("Recherche terminée");}
    //ds.reset_search();
    //delay(2500);
    //return;
  }
  else {
  //On récrit dans la variable du buffer
  snprintf(&buffer_a_envoyer[strlen(buffer_a_envoyer)], SIZE_BUFFER - strlen(buffer_a_envoyer), "&G=");
  if (true/*Serial1*/) {
    Serial1.print(epochToTime());
    Serial1.print(";D;ROM =");
  }
  for( i = 0; i < 8; i++) {
    Serial1.write(' ');
    if (addr[i]<16) {
      if (true/*Serial1*/) {Serial1.print("0");}
      //le "moins" permet d'écrire à gauche
      dtostrf(0, -0, 0, v1_string);
      //On récrit dans la variable du buffer
      snprintf(&buffer_a_envoyer[strlen(buffer_a_envoyer)], SIZE_BUFFER - strlen(buffer_a_envoyer), "%s", v1_string);
    }
    if(true/*Serial1*/){Serial1.print(addr[i], HEX);}
    //le "moins" permet d'écrire à gauche
    dtostrf(addr[i], -0, 0, v1_string);
    //On récrit dans la variable du buffer
    snprintf(&buffer_a_envoyer[strlen(buffer_a_envoyer)], SIZE_BUFFER - strlen(buffer_a_envoyer), "%s", v1_string);
  }

  if (OneWire::crc8(addr, 7) != addr[7]) {
    if(true/*Serial1*/){Serial1.println(";invalid CRC");}
  }
  if(true/*Serial1*/){Serial1.println();}

  if(true/*Serial1*/) {
    Serial1.print(epochToTime());
    Serial1.print(";D;CHIP ");
    Serial1.print(addr[0],HEX);
    //Le premier octet (ROM) indique quelle est le chip (dipositif)
    Serial1.print(" = ");
  }
  switch (addr[0]) {
    case 0x01:
      if(true/*Serial1*/){Serial1.println("DS1990 DS2401");}
      break;
    case 0x02:
      if(true/*Serial1*/){Serial1.println("DS1991");}
      break;
    case 0x04:
      if(true/*Serial1*/){Serial1.println("DS1994");}
      break;
    case 0x05:
      if(true/*Serial1*/){Serial1.println("DS2405");}
      break;
    case 0x06:
      if(true/*Serial1*/){Serial1.println("DS1992");}
      break;
    case 0x08:
      if(true/*Serial1*/){Serial1.println("DS1993");}
      break;
    case 0x0B:
      if(true/*Serial1*/){Serial1.println("DS1985");}
      break;
    case 0x10:
      if(true/*Serial1*/){Serial1.println("DS1820 DS18S20 DS1920");}
      break;
    case 0x12:
      if(true/*Serial1*/){Serial1.println("DS2406");}
      break;
    case 0x21:
      if(true/*Serial1*/){Serial1.println("DS1921");}
      break;
    case 0x22:
      if(true/*Serial1*/){Serial1.println("DS1822");}
      break;
    case 0x24:
      if(true/*Serial1*/){Serial1.println("DS1904");}
      break;
    case 0x28:
      if(true/*Serial1*/){Serial1.print("DS18B20;");}
      if(true/*Serial1*/){Serial1.println("Lecture des données de ce chip...");}
      //On appelle la fonction pour la lecture
      fonction_return_value = lecture_DS18B20(addr);
      //le "moins" permet d'écrire à gauche
      dtostrf(fonction_return_value, -5, 3, v1_string);
      //On récrit dans la variable du buffer
      snprintf(&buffer_a_envoyer[strlen(buffer_a_envoyer)], SIZE_BUFFER - strlen(buffer_a_envoyer), "/DS18B20=%s", v1_string);
      break;
    case 0x29:
      if(true/*Serial1*/){Serial1.println("DS2408");}
      break;
    case 0x36:
      if(true/*Serial1*/){Serial1.println("DS2740");}
      break;
    case 0x3B:
      if(true/*Serial1*/){Serial1.println("DS1825");}
      break;
    case 0x41:
      if(true/*Serial1*/){Serial1.println("DS1923");}
      break;
    default:
      if(true/*Serial1*/){Serial1.println(" n'est pas répertorié.");}
      break;
    }
  }
  if(true/*Serial1*/) {
    Serial1.print(epochToTime());
    Serial1.println(";I;End 1-Wire analysis");
  }
  previousMillis = zerortc.getEpoch();
  if(true/*Serial1*/) {
    Serial1.print(epochToTime());
    Serial1.println(";I;Scan end");
    Serial1.print(epochToTime());
    Serial1.print(";I;buffer = ");
    Serial1.println(buffer_a_envoyer);
  }
  // Serial peripheral (low speed)
  //Serial1.begin(9600);
  // MANAGE SERIAL READ...
  sensorFIFO.pushBuffer((uint8_t*)buffer_a_envoyer, strlen(buffer_a_envoyer));
  //Si on est en mode DEBUG, alors on laisse un petit delai
  PT_END(pt);
}

static int loRaSending(struct pt *pt) {
  PT_BEGIN(pt);
  //////////////////////////////////
  //ENVOIE DES INFORMATIONS VIA LoRa
  //////////////////////////////////
  PT_WAIT_UNTIL(pt, !(sensorFIFO.isEmpty()));
  if(true/*Serial1*/) {
    Serial1.print(epochToTime());
    Serial1.println(";I;Data transmission via LoRa (RF95)");
  }
  
  if (true/*Serial1*/) {Serial1.print(epochToTime());}
  //Activation du LoRa
  if (!rhRDatagram.init()) {
    if(true/*Serial1*/){Serial1.println(";E;LoRa not initialized");}
  } else {
    if(true/*Serial1*/){Serial1.println(";I;LoRa initialized");}
  }
  if (true/*Serial1*/) {
    Serial1.print(epochToTime());
    Serial1.print(";I;FIFO size = ");
    Serial1.println(sensorFIFO.size());
  }
  uint8_t buf[RH_RF95_MAX_MESSAGE_LEN];
  radioDriver.setFrequency(frequence_LoRa);
  radioDriver.setTxPower(puissance_signal_LoRa);
  radioDriver.setSignalBandwidth(bande_passante_LoRa);
  if (true/*Serial1*/) {Serial1.print(epochToTime());}
  if (!(sensorFIFO.isEmpty())) {
    sensorFIFO.peekBuffer(tmpBuffer, SIZE_BUFFER);
    JBCDIC jbcdic;
    uint8_t tmpBuffer2[SIZE_BUFFER];
    int counter = jbcdic.encode_to_jbcdic((char*)tmpBuffer, sensorFIFO.peek(), tmpBuffer2, SIZE_BUFFER);
    
    if(rhRDatagram.sendtoWait(tmpBuffer2, counter, SERVER_ADDRESS)) {
      sensorFIFO.popBuffer(tmpBuffer, SIZE_BUFFER);
      if (true/*Serial1*/) {
        Serial1.println(";I;Packet sent");
      }
      // Now wait for a reply from the server
    }
    else{
      if (true/*Serial1*/) {
        Serial1.println(";W;Packet not received");
      }
    }
    if (true/*Serial1*/) {Serial1.println("");}
  }
  PT_END(pt);
}

void EIC_ISR(void) {
  buttonFlag = true;  // toggle buttonFlag by XORing it against true
}

void alarmMatch(void)
{
  alarmFlag = true; // Set flag
}

uint32_t epochToTime(void) {
  uint32_t epochToSec = zerortc.getEpoch() - EPOCH_TIME;
  return epochToSec;
}

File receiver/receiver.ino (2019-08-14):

#include "FS.h"
#include "SD.h"
#include "SPI.h"
#include <Wire.h>
#include "pt.h"
#include "FIFO.h"
// We are not encoding JSON but URL ...
#include "JBCDIC.h"

// LoRa Network Address
#define SERVER_ADDRESS 120

#ifdef ARDUINO_SAMD_MKRWAN1300
  // no screen, no Wifi but LoRa
  #include "RH_RF95.h"
  #include "RHReliableDatagram.h"
#elif ARDUINO_FEATHER_ESP32
  #include <Adafruit_GFX.h>
  #include <Adafruit_SSD1306.h>
  #include "RTClib.h"
  #include <WiFiClientSecure.h>
  #include <WiFiClient.h>
  #include "RH_RF95.h"
  #include "RHReliableDatagram.h"
  #include "IotWebConf.h"

  // When stacking ADAFruit boards (ESP32, OLED, RTC+SD card, LoRa board), PCF8523 is the RTC used
  RTC_PCF8523 rtc;
  Adafruit_SSD1306 display = Adafruit_SSD1306(128, 32, &Wire);

  #define RFM95_RST     27
  #define RFM95_CS      14 
  #define RFM95_INT     32

  // Singleton instance of the radio driver
  RH_RF95 radioDriver(RFM95_CS, RFM95_INT);
  
  RHReliableDatagram rhRDatagram(radioDriver, SERVER_ADDRESS);
#elif ARDUINO_M5Stack_Core_ESP32
  // No LoRa and Another type of screen...
  #include <WiFiClientSecure.h>
  #include <WiFiClient.h>
  #include "IotWebConf.h"
#endif

// PHENICS is not supporting HTTPS
#undef __HTTPS__

// OLED FeatherWing buttons map to different pins depending on board:x  
#if defined(ESP8266)
  #define BUTTON_A  0
  #define BUTTON_B 16
  #define BUTTON_C  2
#elif defined(ESP32)
  #define BUTTON_A 15
  #define BUTTON_B 32
  #define BUTTON_C 14
#elif defined(ARDUINO_STM32_FEATHER)
  #define BUTTON_A PA15
  #define BUTTON_B PC7
  #define BUTTON_C PC5
#elif defined(TEENSYDUINO)
  #define BUTTON_A  4
  #define BUTTON_B  3
  #define BUTTON_C  8
#elif defined(ARDUINO_FEATHER52832)
  #define BUTTON_A 31
  #define BUTTON_B 30
  #define BUTTON_C 27
#else // 32u4, M0, M4, nrf52840 and 328p
  #define BUTTON_A  9
  #define BUTTON_B  6
  #define BUTTON_C  5
#endif

//TODO: For Arduino MKR ?
// ARDUINO_STM32_FEATHER
#define CONFIG_PIN 15
#define STATUS_PIN 13

// IotWebConf:
#define HTTP_PORT 80
#define STRING_LEN 128
#define CONFIG_VERSION "dem2"

// LoRa:
//Fréquence d'utilisation (par defaut 869.35 MHz)
float frequence_LoRa = 869.35;
//Bande passante utilisée (par defaut : 62,5 KHz)
long bande_passante_LoRa = 62500;
//Puissance utilisée (par defaut : 10 mW)
uint8_t puissance_signal_LoRa = 10;

//Certificat SSL LOCAL
const char* test_root_ca2= \
"-----BEGIN CERTIFICATE-----\n" \
"MIIGfTCCBWWgAwIBAgIQKr426ykpq7kEPBdeDeXrWjANBgkqhkiG9w0BAQsFADBy\n" \
"MQswCQYDVQQGEwJVUzELMAkGA1UECBMCVFgxEDAOBgNVBAcTB0hvdXN0b24xFTAT\n" \
"BgNVBAoTDGNQYW5lbCwgSW5jLjEtMCsGA1UEAxMkY1BhbmVsLCBJbmMuIENlcnRp\n" \
"ZmljYXRpb24gQXV0aG9yaXR5MB4XDTE5MDIwNDAwMDAwMFoXDTE5MDUwNTIzNTk1\n" \
"OVowIzEhMB8GA1UEAxMYeGF2aWVyLW1hcnRpbi10cmFkaW5nLmZyMIIBIjANBgkq\n" \
"hkiG9w0BAQEFAAOCAQ8AMIIBCgKCAQEAw6fc7jpyPqT7m6P2ltdSMfWfy0NSBKWh\n" \
"bHrSFPX8agMwn6T1+9yV1B8HIXkOTx7oX4DIrL2d8rYG13Rp2EhT2+Uomdq8AeXk\n" \
"TI8GHqlF76+KKpfKFsKMWSPVZcZJ3MMvP0g4g0mblnRy6iq6e/DJHQfh3aGFHYlP\n" \
"+uda1a2eZ85Utnz6nFEOufYEvDkynn53MWEuWT94ALdSn2E3f6IRGW2SjRi9fQ5N\n" \
"PzYeLfPlcjoqpZOkuQmbNv9gRu1/2x9iWQCLRnv6/Aphfd794YgveHuFZXN3PNa6\n" \
"BFuxzdNuPokWFU1PXIvlo8X9oVpLA6uiJhZjNK8HG/eF7tDJnaxvTQIDAQABo4ID\n" \
"XDCCA1gwHwYDVR0jBBgwFoAUfgNaZUFrp34K4bidCOodjh1qx2UwHQYDVR0OBBYE\n" \
"FGFSDqIWVkWTgpP1EQXIOnNuDmb5MA4GA1UdDwEB/wQEAwIFoDAMBgNVHRMBAf8E\n" \
"AjAAMB0GA1UdJQQWMBQGCCsGAQUFBwMBBggrBgEFBQcDAjBPBgNVHSAESDBGMDoG\n" \
"CysGAQQBsjEBAgI0MCswKQYIKwYBBQUHAgEWHWh0dHBzOi8vc2VjdXJlLmNvbW9k\n" \
"by5jb20vQ1BTMAgGBmeBDAECATBMBgNVHR8ERTBDMEGgP6A9hjtodHRwOi8vY3Js\n" \
"LmNvbW9kb2NhLmNvbS9jUGFuZWxJbmNDZXJ0aWZpY2F0aW9uQXV0aG9yaXR5LmNy\n" \
"bDB9BggrBgEFBQcBAQRxMG8wRwYIKwYBBQUHMAKGO2h0dHA6Ly9jcnQuY29tb2Rv\n" \
"Y2EuY29tL2NQYW5lbEluY0NlcnRpZmljYXRpb25BdXRob3JpdHkuY3J0MCQGCCsG\n" \
"AQUFBzABhhhodHRwOi8vb2NzcC5jb21vZG9jYS5jb20wgbIGA1UdEQSBqjCBp4IY\n" \
"eGF2aWVyLW1hcnRpbi10cmFkaW5nLmZygh1tYWlsLnhhdmllci1tYXJ0aW4tdHJh\n" \
"ZGluZy5mcoIod3d3Lnhhdmllci1tYXJ0aW4tdHJhZGluZy5kYXRhY2hldmV1LmNv\n" \
"bYIcd3d3Lnhhdmllci1tYXJ0aW4tdHJhZGluZy5mcoIkeGF2aWVyLW1hcnRpbi10\n" \
"cmFkaW5nLmRhdGFjaGV2ZXUuY29tMIIBBAYKKwYBBAHWeQIEAgSB9QSB8gDwAHYA\n" \
"u9nfvB+KcbWTlCOXqpJ7RzhXlQqrUugakJZkNo4e0YUAAAFotdADvwAABAMARzBF\n" \
"AiAv0NCyIgZ2cHpI+jClurKHwtSNZWXiXcU64fytrKsO5QIhAJ2QK9BfoUbjowwH\n" \
"1BF32g5spEbii9CyWjKD2WD4qstfAHYAdH7agzGtMxCRIZzOJU9CcMK//V5CIAjG\n" \
"NzV55hB7zFYAAAFotdAEFAAABAMARzBFAiAaCKsJw3yo6yuLIsz1E5v6XwkuRT4Q\n" \
"qSDYl+1JW8pz4gIhAIxbIIb1K81EQAaE3m8P/1C4K8dG+sb4pHv8t0Qvd61wMA0G\n" \
"CSqGSIb3DQEBCwUAA4IBAQAthmGhMZXzRFpagH7+xPsxFbDEddxLOcLjU9svff9q\n" \
"GWXjK0PhzFjAQfFomzRkhcu3w4sVy0A0DcmMkAcAHi2H3KMlqT7xMpa4CE/hfuZk\n" \
"eJ4V4AXqiTJydUafvfYhQlNO3UnU68lmo18J4PgUw19Urxu2jERyrzsY4usqpvgb\n" \
"7Qw8ZJxK2gR/RYJKec74opj48O4t8EjPgONM9/SKVyQoNZFcUgBiwoylQ9yHrOpm\n" \
"M9uDLnGHxSL11zBUGkjX3Ym/Zxcf4sa+TeDWrt0F89PTGvChMK1rj54hbTkEaodA\n" \
"/A3hZ+wpT3sK6uWF/fenyZNt4/mgxoSbkYS/uaI5HSMD\n" \
"-----END CERTIFICATE-----\n";

#if __HTTPS__
WiFiClientSecure client;
#else
WiFiClient client;
#endif

//Taille FIXE Maximale du buffer d'envoi LoRa
#define SIZE_URL_HTTPS 200
//Variable a envoyer via LoRa
char URL_HTTPS[SIZE_URL_HTTPS];

static struct pt receivingPT, sendDataPT;

const char thingName[] = "Akuino";
const char wifiInitialApPassword[] = "12345678";

char hostServer[STRING_LEN];
boolean formValidator();
void configSaved();

DNSServer dnsServer;
WebServer server(80);

IotWebConf iotWebConf(thingName, &dnsServer, &server, wifiInitialApPassword, CONFIG_VERSION);

FIFO serverfifo;

char daysOfTheWeek[7][12] = {"Dimanche", "Lundi", "Mardi", "Mercredi", "Jeudi", "Vendredi", "Samedi"};

void setup() {
  Serial.begin(115200);
  
  iotWebConf.setStatusPin(STATUS_PIN);
  iotWebConf.setConfigPin(CONFIG_PIN);
  iotWebConf.setConfigSavedCallback(&configSaved);
  iotWebConf.setFormValidator(&formValidator);

  iotWebConf.init();

  server.on("/", handleRoot);
  server.on("/config", []{ iotWebConf.handleConfig(); });
  server.onNotFound([](){ iotWebConf.handleNotFound(); });

//TODO: For Arduino MKR ?
  if (! rtc.begin()) {
    if(Serial) {
      Serial.print(millis());
      Serial.println(";E;Couldn't find RTC");
    }
  }

  if (! rtc.initialized()) {
    if(Serial) {
      Serial.print(millis());
      Serial.println(";E;RTC not running!");
    }
    // following line sets the RTC to the date & time this sketch was compiled
    rtc.adjust(DateTime(F(__DATE__), F(__TIME__)));
    // This line sets the RTC with an explicit date & time, for example to set
    // January 21, 2014 at 3am you would call:
    // rtc.adjust(DateTime(2014, 1, 21, 3, 0, 0));
  }

//TODO: For Arduino MKR ?
  display.begin(SSD1306_SWITCHCAPVCC, 0x3C); // Address 0x3C for 128x32
  display.display();
  delay(1000);
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

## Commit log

2018-06-27 Changement sur la sécurité des transmissions
    Autres à venir cet aprèsm
2018-08-25 Update README.md
    Add description of 1-Wire bus integration
2018-09-12 1-Wire connexion to host?
2019-02-28 1-Wire is 3.3V tolerant in most cases
2019-04-01 Eagle files for the power control board
    [PowerNest.brd, PowerNest.sch]
2019-05-20 Apport de Badr
2019-05-20 ESP32 connections
2019-05-20 Relay1 inversion!
2019-07-25 finalisation envoi des données sur le serveur
2019-07-30 UBCDIC plutot que JBCDIC!
2019-08-14 Derniere modif de Romain

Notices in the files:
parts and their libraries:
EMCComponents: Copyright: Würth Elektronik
